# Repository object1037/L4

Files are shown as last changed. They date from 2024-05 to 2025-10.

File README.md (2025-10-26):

# L4

L4

The L4 is a 50% wireless split keyboard with an ortholinear layout.

- Keys: 52
- Switch: Choc V2 / MX
- Power: LiPo / CR2032
- Mount: Gasket / M2

## BOM

- Seeed XIAO BLE nRf52840 x 2
- Switch x 52
- Keycap x 52
- Diode(SOD123) x 52
- DP3T switch(SK23D07) x 2

### CR2032

- CR2032 battery x 4
- CR2032 holder(BC-2001) x 4
- Schottky diode(SOD123) x 4
- Capacitor(100uF, 3216) x 2
- PMOS(SSM3J332R) x 2

### LiPo

- LiPo battery x 2
- PH connector(side) x 2

### Acrylic case

- Case x 1
- M2 spacer
  - 1.6-2mm x 6
  - 3.5mm x 8
  - 6mm x 12
- M2 screw
  - 5mm x 10
  - 8mm x 6
  - 10mm x 8

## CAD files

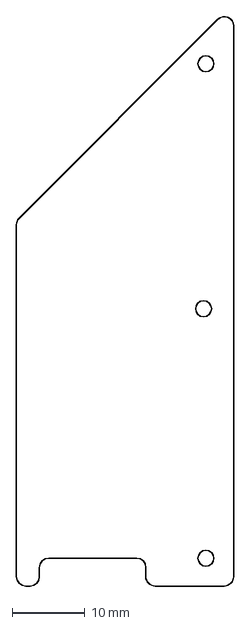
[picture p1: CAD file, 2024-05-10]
hardware/case/l_upper.dxf
29.8 x 78.3 mm

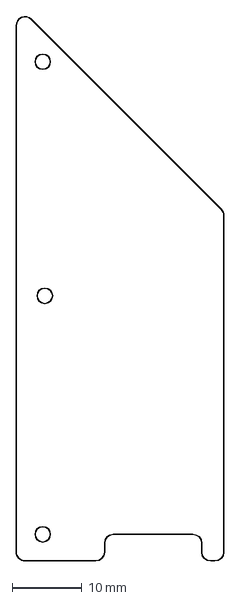
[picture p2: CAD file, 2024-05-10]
hardware/case/r_upper.dxf
29.8 x 78.3 mm

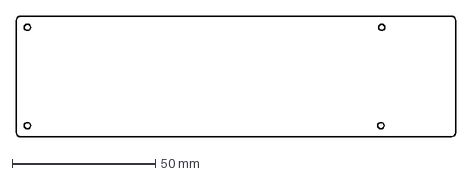
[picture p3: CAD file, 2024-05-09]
hardware/case/r_bottom.dxf
153.0 x 41.9 mm

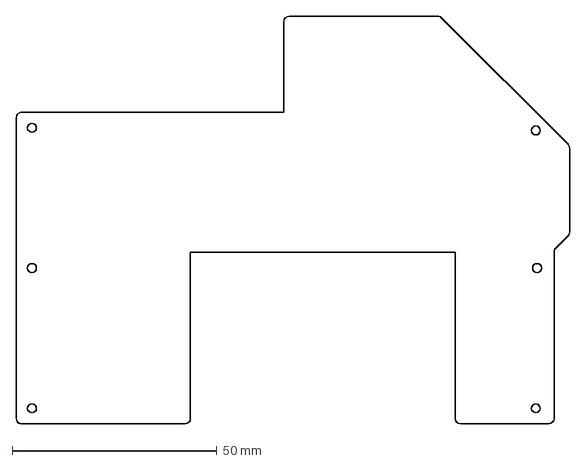
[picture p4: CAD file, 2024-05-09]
hardware/case/r_base.dxf
135.3 x 99.7 mm

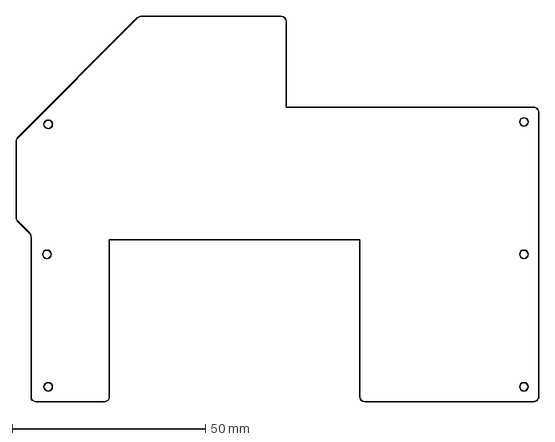
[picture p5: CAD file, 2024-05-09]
hardware/case/l_base.dxf
135.3 x 99.7 mm

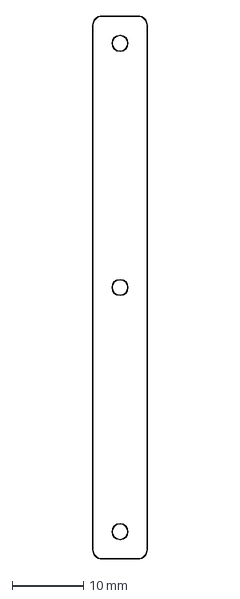
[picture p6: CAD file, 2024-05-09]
hardware/case/r_outer.dxf
7.62 x 76.2 mm

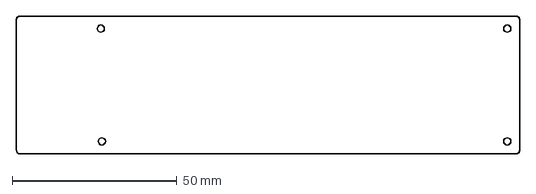
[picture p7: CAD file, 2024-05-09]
hardware/case/l_bottom.dxf
153.0 x 41.9 mm

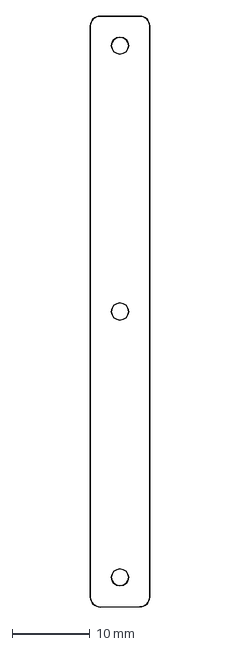
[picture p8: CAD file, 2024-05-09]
hardware/case/l_outer.dxf
7.62 x 76.2 mm

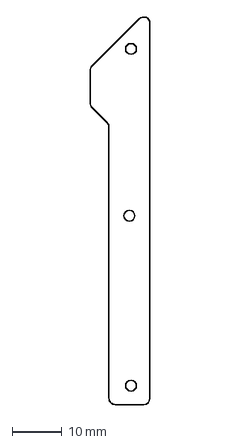
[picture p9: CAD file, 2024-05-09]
hardware/case/l_inner.dxf
12.1 x 78.3 mm

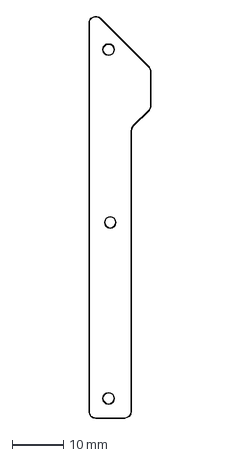
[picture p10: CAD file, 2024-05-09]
hardware/case/r_inner.dxf
12.1 x 78.3 mm

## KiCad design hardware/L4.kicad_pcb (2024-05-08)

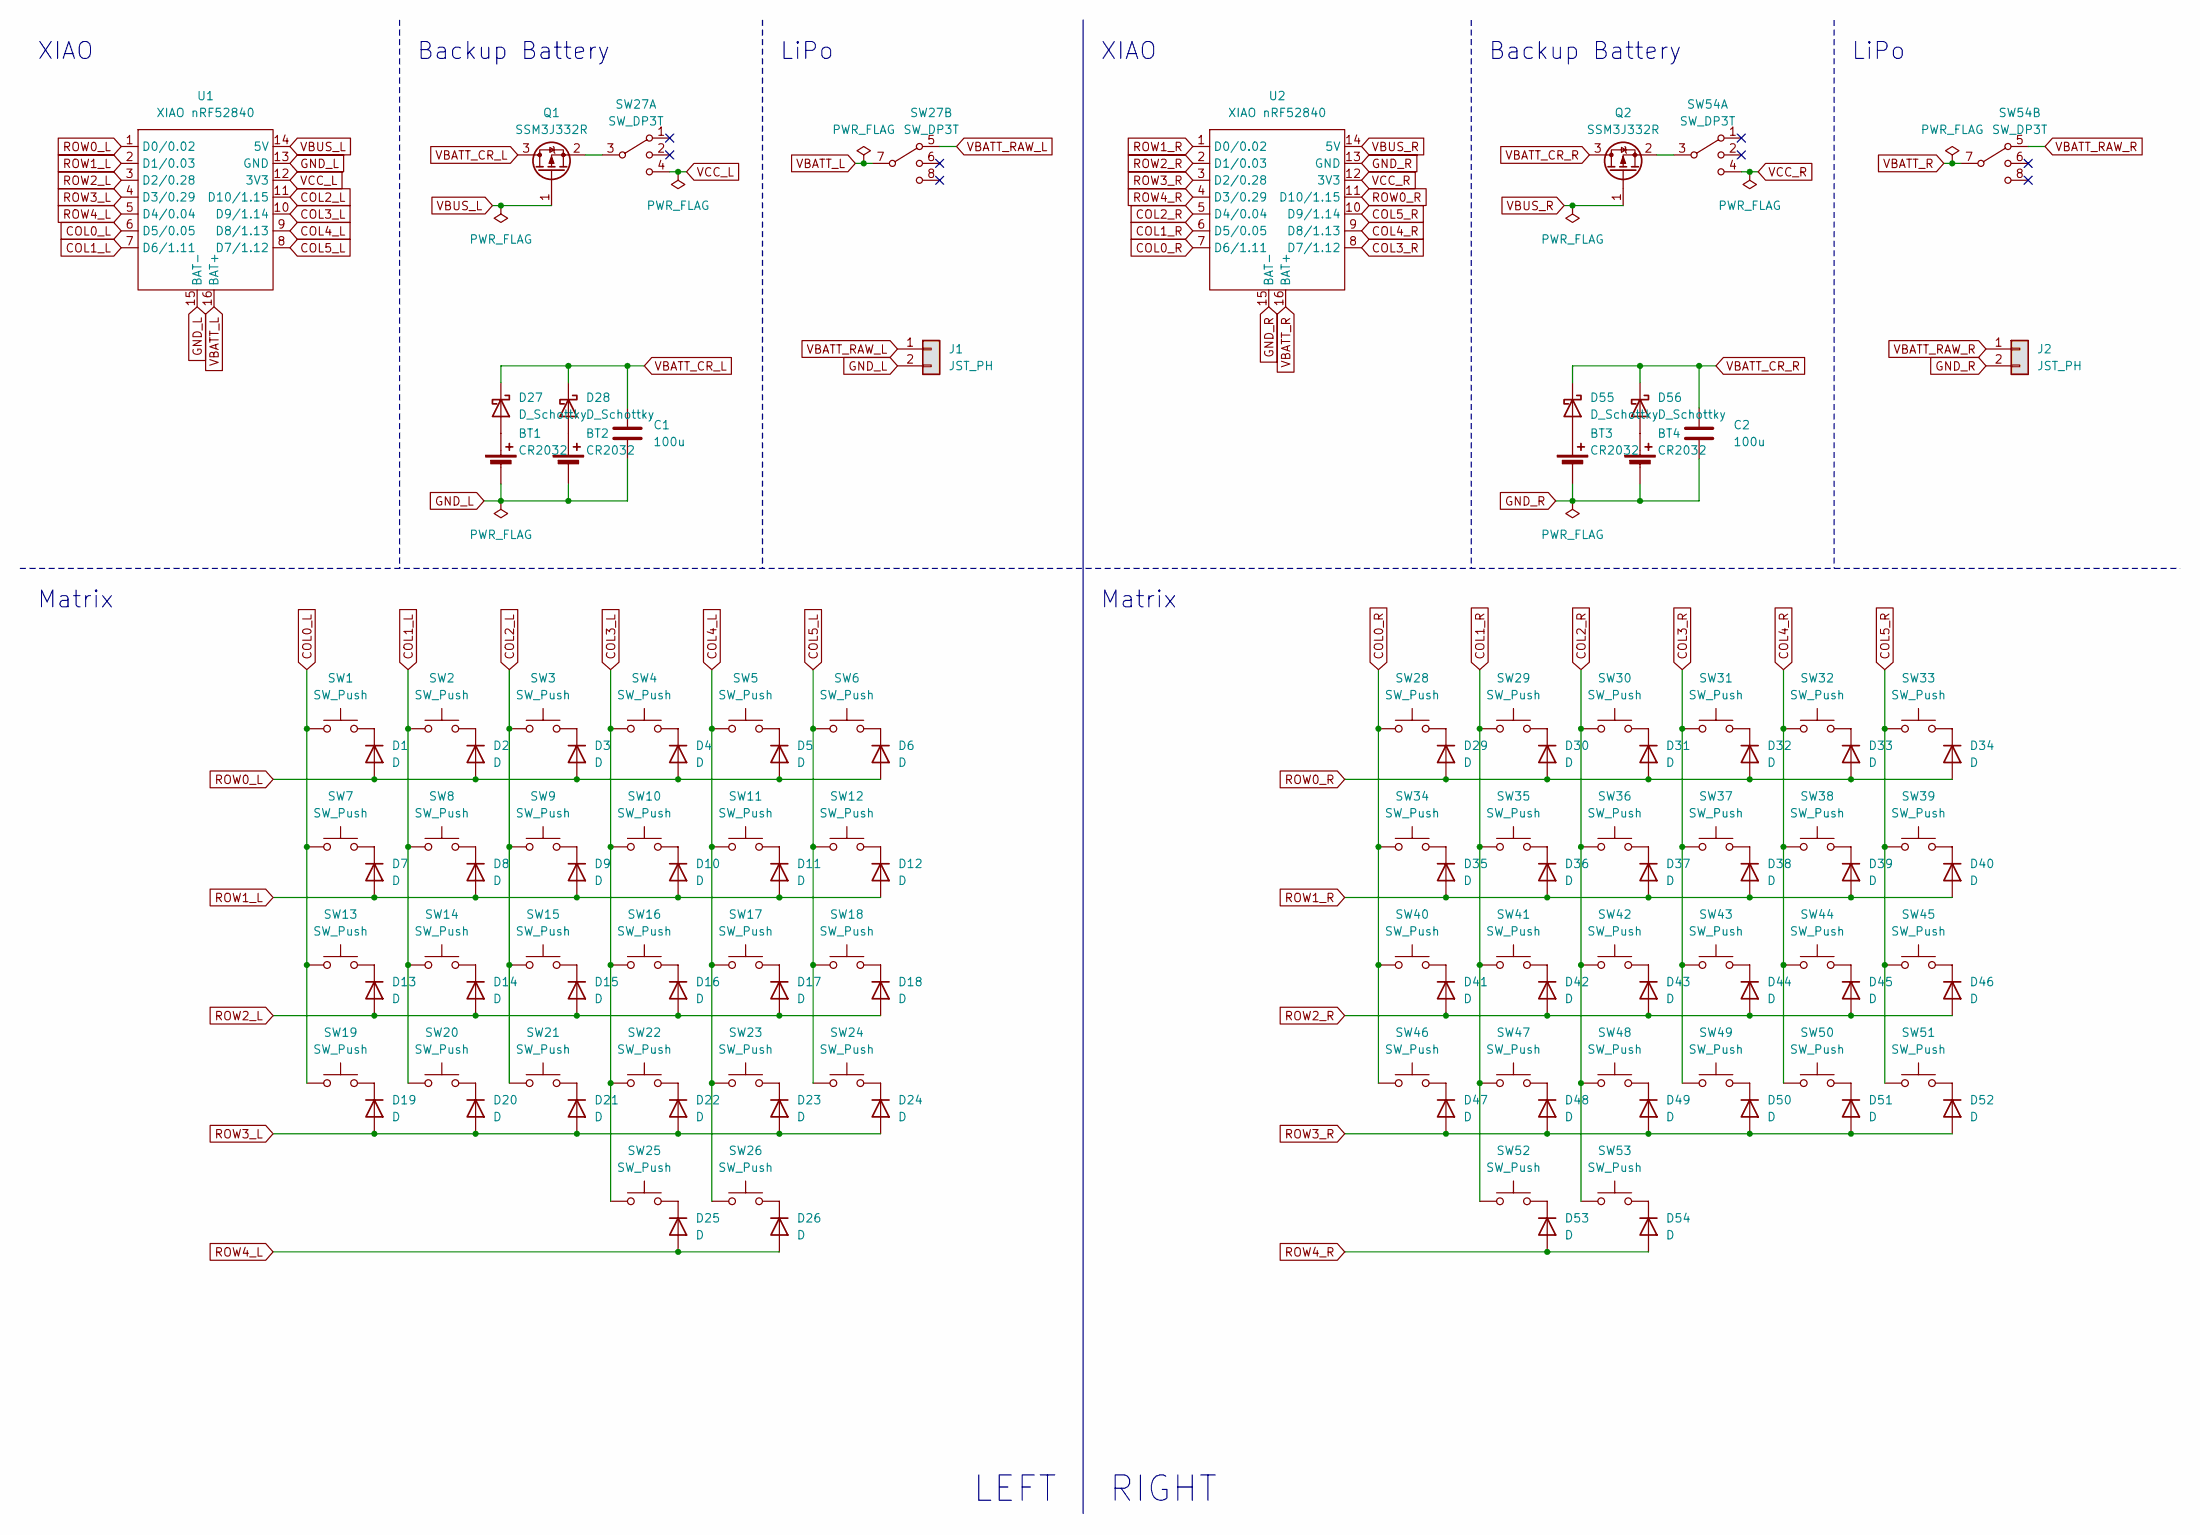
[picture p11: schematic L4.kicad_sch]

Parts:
BT1, BT2, BT3, BT4: CR2032; BatteryHolder_Multicomp_BC-2001_1x2032
C1, C2: 100u; C_1206_3216Metric_Pad1.33x1.80mm_HandSolder
D1, D2, D3, D4, D5, D6, D7, D8, D9, D10, D11, D12, D13, D14, D15, D16, D17, D18, D19, D20, D21, D22, D23, D24, D25, D26, D29, D30, D31, D32, D33, D34, D35, D36, D37, D38, D39, D40, D41, D42, D43, D44, D45, D46, D47, D48, D49, D50, D51, D52, D53, D54: D; D_SOD-123
D27, D28, D55, D56: D_Schottky; D_SOD-123
J1, J2: JST_PH; JST_PH_S2B-PH-K_1x02_P2.00mm_Horizontal
Q1, Q2: SSM3J332R; SOT-23-3
SW1, SW2, SW3, SW4, SW5, SW6, SW7, SW8, SW9, SW10, SW11, SW12, SW13, SW14, SW15, SW16, SW17, SW18, SW19, SW20, SW21, SW22, SW23, SW24, SW25, SW26, SW28, SW29, SW30, SW31, SW32, SW33, SW34, SW35, SW36, SW37, SW38, SW39, SW40, SW41, SW42, SW43, SW44, SW45, SW46, SW47, SW48, SW49, SW50, SW51, SW52, SW53: SW_Push; keyswitch_cherrymx_choc12_1u
SW27, SW54: SW_DP3T; SK23D07
U1, U2: XIAO nRF52840; XIAO_nrf52840

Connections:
COL0_L: SW1.1, SW7.1, SW13.1, SW19.1, U1.6 (D5/0.05)
COL0_R: SW28.1, SW34.1, SW40.1, SW46.1, U2.7 (D6/1.11)
COL1_L: SW2.1, SW8.1, SW14.1, SW20.1, U1.7 (D6/1.11)
COL1_R: SW29.1, SW35.1, SW41.1, SW47.1, SW52.1, U2.6 (D5/0.05)
COL2_L: SW3.1, SW9.1, SW15.1, SW21.1, U1.11 (D10/1.15)
COL2_R: SW30.1, SW36.1, SW42.1, SW48.1, SW53.1, U2.5 (D4/0.04)
COL3_L: SW4.1, SW10.1, SW16.1, SW22.1, SW25.1, U1.10 (D9/1.14)
COL3_R: SW31.1, SW37.1, SW43.1, SW49.1, U2.8 (D7/1.12)
COL4_L: SW5.1, SW11.1, SW17.1, SW23.1, SW26.1, U1.9 (D8/1.13)
COL4_R: SW32.1, SW38.1, SW44.1, SW50.1, U2.9 (D8/1.13)
COL5_L: SW6.1, SW12.1, SW18.1, SW24.1, U1.8 (D7/1.12)
COL5_R: SW33.1, SW39.1, SW45.1, SW51.1, U2.10 (D9/1.14)
GND_L: BT1.2 (-), BT2.2 (-), C1.2, J1.2, U1.13 (GND), U1.15 (BAT-)
GND_R: BT3.2 (-), BT4.2 (-), C2.2, J2.2, U2.13 (GND), U2.15 (BAT-)
unnamed: BT1.1 (+), D27.2 (A)
unnamed: BT2.1 (+), D28.2 (A)
unnamed: BT3.1 (+), D55.2 (A)
unnamed: BT4.1 (+), D56.2 (A)
unnamed: D1.1 (K), SW1.2
unnamed: D2.1 (K), SW2.2
unnamed: D3.1 (K), SW3.2
unnamed: D4.1 (K), SW4.2
unnamed: D5.1 (K), SW5.2
unnamed: D6.1 (K), SW6.2
unnamed: D7.1 (K), SW7.2
unnamed: D8.1 (K), SW8.2
unnamed: D9.1 (K), SW9.2
unnamed: D10.1 (K), SW10.2
unnamed: D11.1 (K), SW11.2
unnamed: D12.1 (K), SW12.2
unnamed: D13.1 (K), SW13.2
unnamed: D14.1 (K), SW14.2
unnamed: D15.1 (K), SW15.2
unnamed: D16.1 (K), SW16.2
unnamed: D17.1 (K), SW17.2
unnamed: D18.1 (K), SW18.2
unnamed: D19.1 (K), SW19.2
unnamed: D20.1 (K), SW20.2
unnamed: D21.1 (K), SW21.2
unnamed: D22.1 (K), SW22.2
unnamed: D23.1 (K), SW23.2
unnamed: D24.1 (K), SW24.2
unnamed: D25.1 (K), SW25.2
unnamed: D26.1 (K), SW26.2
unnamed: D29.1 (K), SW28.2
unnamed: D30.1 (K), SW29.2
unnamed: D31.1 (K), SW30.2
unnamed: D32.1 (K), SW31.2
unnamed: D33.1 (K), SW32.2
unnamed: D34.1 (K), SW33.2
unnamed: D35.1 (K), SW34.2
unnamed: D36.1 (K), SW35.2
unnamed: D37.1 (K), SW36.2
unnamed: D38.1 (K), SW37.2
unnamed: D39.1 (K), SW38.2
unnamed: D40.1 (K), SW39.2
unnamed: D41.1 (K), SW40.2
unnamed: D42.1 (K), SW41.2
unnamed: D43.1 (K), SW42.2
unnamed: D44.1 (K), SW43.2
unnamed: D45.1 (K), SW44.2
unnamed: D46.1 (K), SW45.2
unnamed: D47.1 (K), SW46.2
unnamed: D48.1 (K), SW47.2
unnamed: D49.1 (K), SW48.2
unnamed: D50.1 (K), SW49.2
unnamed: D51.1 (K), SW50.2
unnamed: D52.1 (K), SW51.2
unnamed: D53.1 (K), SW52.2
unnamed: D54.1 (K), SW53.2
unnamed: Q1.2 (S), SW27.3
unnamed: Q2.2 (S), SW54.3
ROW0_L: D1.2 (A), D2.2 (A), D3.2 (A), D4.2 (A), D5.2 (A), D6.2 (A), U1.1 (D0/0.02)
ROW0_R: D29.2 (A), D30.2 (A), D31.2 (A), D32.2 (A), D33.2 (A), D34.2 (A), U2.11 (D10/1.15)
ROW1_L: D7.2 (A), D8.2 (A), D9.2 (A), D10.2 (A), D11.2 (A), D12.2 (A), U1.2 (D1/0.03)
ROW1_R: D35.2 (A), D36.2 (A), D37.2 (A), D38.2 (A), D39.2 (A), D40.2 (A), U2.1 (D0/0.02)
ROW2_L: D13.2 (A), D14.2 (A), D15.2 (A), D16.2 (A), D17.2 (A), D18.2 (A), U1.3 (D2/0.28)
ROW2_R: D41.2 (A), D42.2 (A), D43.2 (A), D44.2 (A), D45.2 (A), D46.2 (A), U2.2 (D1/0.03)
ROW3_L: D19.2 (A), D20.2 (A), D21.2 (A), D22.2 (A), D23.2 (A), D24.2 (A), U1.4 (D3/0.29)
ROW3_R: D47.2 (A), D48.2 (A), D49.2 (A), D50.2 (A), D51.2 (A), D52.2 (A), U2.3 (D2/0.28)
ROW4_L: D25.2 (A), D26.2 (A), U1.5 (D4/0.04)
ROW4_R: D53.2 (A), D54.2 (A), U2.4 (D3/0.29)
VBATT_CR_L: C1.1, D27.1 (K), D28.1 (K), Q1.3 (D)
VBATT_CR_R: C2.1, D55.1 (K), D56.1 (K), Q2.3 (D)
VBATT_L: SW27.7, U1.16 (BAT+)
VBATT_R: SW54.7, U2.16 (BAT+)
VBATT_RAW_L: J1.1, SW27.5
VBATT_RAW_R: J2.1, SW54.5
VBUS_L: Q1.1 (G), U1.14 (5V)
VBUS_R: Q2.1 (G), U2.14 (5V)
VCC_L: SW27.4, U1.12 (3V3)
VCC_R: SW54.4, U2.12 (3V3)

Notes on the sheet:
XIAO
LiPo
RIGHT
Matrix
Backup Battery
LEFT

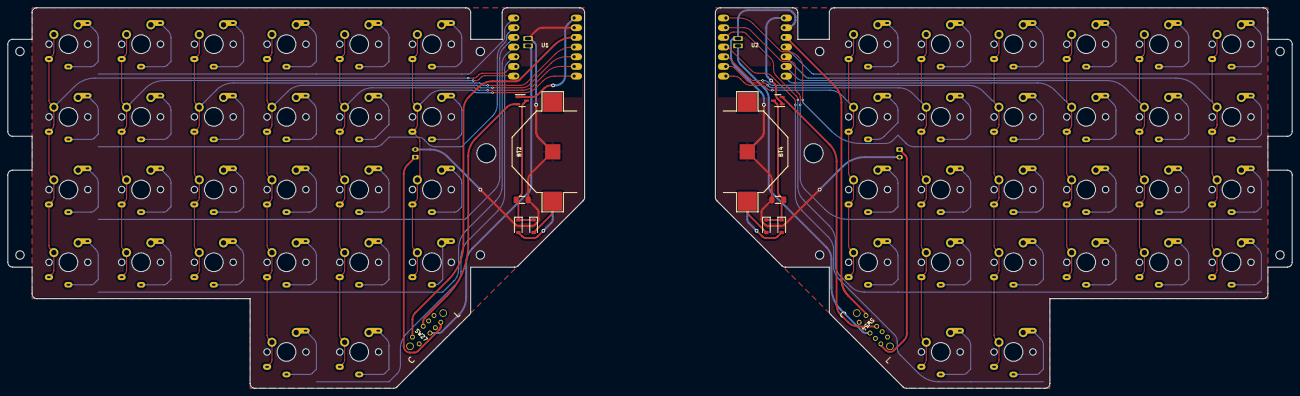
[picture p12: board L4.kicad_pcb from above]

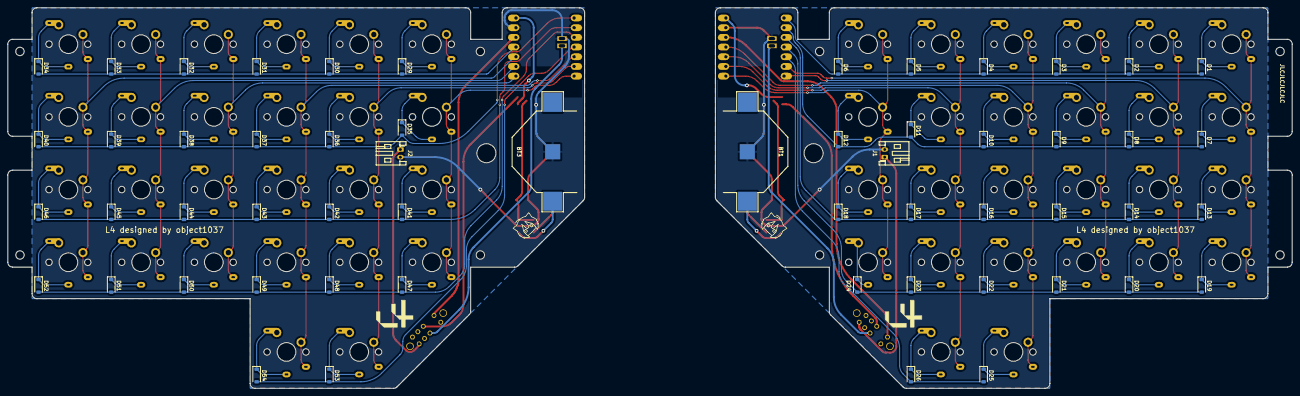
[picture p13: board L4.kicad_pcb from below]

Board: 2 copper layers, 336.5 x 99.7 mm, 122 parts (56 on the bottom side), 92 nets.

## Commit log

2024-05-04 init kicad project
    [L4.kicad_pcb, L4.kicad_sch]
2024-05-04 write left half schematic
    [L4.kicad_sch]
2024-05-05 finish right halve
    [L4.kicad_sch]
2024-05-05 fix switch position
    [L4.kicad_sch]
2024-05-05 link footprints
    [L4.kicad_sch]
2024-05-06 finish part layout
    [L4.kicad_pcb, L4.kicad_sch]
2024-05-07 finish routing
    [L4.kicad_pcb, L4.kicad_sch]
2024-05-07 fillet left half
    [L4.kicad_pcb]
2024-05-08 apply fillets
    [L4.kicad_pcb]
2024-05-08 layout boards
2024-05-08 plot gerber
    [L4-B_Cu.gbr, L4-B_Mask.gbr, L4-B_Paste.gbr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]
2024-05-09 fix edge cut
    [L4-B_Cu.gbr, L4-B_Mask.gbr, L4-B_Paste.gbr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]
2024-05-09 output DXF files
    [l_base.dxf, l_bottom.dxf, l_inner.dxf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]
2024-05-10 add upper cover
    [l_upper.dxf, r_upper.dxf]
